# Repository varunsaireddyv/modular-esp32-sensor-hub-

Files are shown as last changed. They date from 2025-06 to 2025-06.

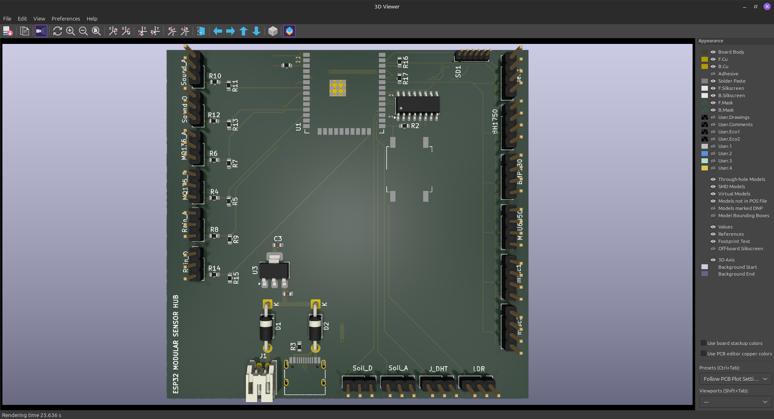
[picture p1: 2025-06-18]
Images/PCB_F.png

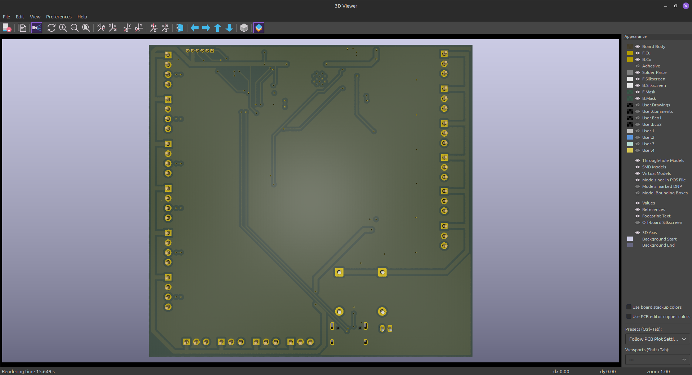
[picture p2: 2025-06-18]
Images/PCB_B.png

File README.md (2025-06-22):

# modular-esp32-sensor-hub-
Introduction:

This project is a modular ESP32-based sensor hub designed for rapid prototyping and monitoring environements. It supports a wide range of sensors through hot-swappable connectors, with onboard SD card logging, and runs off a 5v li-ion battery. The goal is to offer a deployable, plug-and-play embedded system that’s both scalable and user-friendly.

Primary Design Goals:

Modularity:hot-swappable sensor ports for analog, digital, and I2C devices, swapable power source, programable ESP board

Deployability:standalone and swapable power and onboard storage, light weight custom ESP 32 WROOM 32D board

Plug-and-play:Firmware pre installed and no user input required exept for conecting sensors to premaped sensor pins

---

## Features

- ESP32-WROOM-32D core (Wi-Fi + BLE)
- 13 modular sensor ports: digital, analog, and I2C
- MicroSD card support (SPI) for data logging
- 0.96" OLED screen support via I2C
- Shared I2C bus (GPIO21/GPIO22) with pull-up planning
- Dual voltage rails: 5V (VBUS) and 3.3V (via AMS1117 regulator)
- USB or Li-ion battery input with diode-based auto-switching
- Ground stitched bottom layer with dedicated signal routing on top
- Wide traces (1mm) for power, separate analog and digital zones
- Modular firmware (coming soon)

---

## Pin Mapping

| Function | GPIO Pin |
|---|---|
| I2C SDA | GPIO21 |
| I2C SCL | GPIO22 |
| SD Card CS | GPIO5 |
| SD Card CLK | GPIO18 |
| SD Card MOSI | GPIO23 |
| SD Card MISO | GPIO19 |
| Analog Sensor 1 | GPIO32 |
| Analog Sensor 2 | GPIO33 |
| Digital Sensor 1 | GPIO25 |
| Digital Sensor 2 | GPIO26 |
| Digital Sensor 3 | GPIO27 |
| Digital Sensor 4 | GPIO14 |
| Digital Sensor 5 | GPIO12 |
| Digital Sensor 6 | GPIO13 |
| OLED (I2C) | Shared |
| I2C Misc Ports 1-2  | Shared |

> All analog lines use 1k/2k voltage dividers to drop from 5V to 3.3V safe levels for the ESP32. All sensors are routed through XH-3P connectors with GND, VCC, and Signal/I2C.

---

## Supported Sensors(Default in Firmware)

### Analog / Digital Sensors
- MQ135 (Air Quality)
- DHT22 (Temp & Humidity)
- Raindrop Sensor
- Sound Sensor (x2)
- Soil Moisture
- LDR (Light)
- IR Receiver

### I2C Sensors & Modules
- MPU6050 (Accel + Gyro)
- BME280 (Temp + Pressure + Humidity)
- BH1750 (Light)
- OLED Display

---

## Included Files/Folders

- Schematic: `ESP32_WROOM_D.kicad_sch`
- Board Layout: `PCB_main.kicad_pcb`
- Schematic PNG preview: `Schemtaic.png`
- 3D render: `PCB.png`
- 3D render front: `PCB_F.png`
- 3D render back: `PCB_B.png`
- License: MIT
- Firmware: src/, include/,  lib/, "platform.ini"
- Documents: "ERC", "DRC", "Datasheet", "Pin_mapping"

---

## Firmware flow

main.cpp :
-Calls SensorManager.begin() → initializes I2C, sets up pins
-Calls SensorManager.detectConnectedSensors() → auto-detects attached sensors
-Calls SensorManager.readAll() repeatedly inside loop() to read & print sensor data

sensormanger.cpp/.h :
-Defines bool flags for each supported sensor
-Each sensor has its own analogRead() or I2C detection logic
-readAll() only reads sensors that were marked as detected(bool=true)

pins.h :
-Central place to edit pin numbers (for future boards or remapping)
-Also includes notes on analog/digital/I2C mappings

---

## Adding own sensors

You can plug in any new sensor to unused analog/digital/I2C ports. Here’s how to support it in firmware:

Step 1 : Wiring :

-Connect the sensor to a free port (check Pin Mapping table)
-Use correct GND/VCC/SIG (XH-3P)

step 2 : Modify "sensormanger.h" :
   
  -Add a flag for presence detection :
      
    extern bool NEW_SENSOR_present;

step 3 : Modify "pins.h" :
   
  -define your sensor with its GIO pin :
  
    #define NEW_SENSOR_PIN ##   //replace ## with GIO pin(can be found in sensor data sheet)

step 4 : Modify "sensormanger.cpp" :

  -In detectConnectedSensors add :
  
    -if (analogRead(NEW_SENSOR_PIN) > 50) NEW_SENSOR_present = true;   //(for analog sensors)
    -if (analogRead(NEW_SENSOR_PIN) > 50) NEW_SENSOR_present = true;   //(for digital sensors)
    -Check sensor library for I2C (differs from sensor to sensor reffer sesnormanager.cpp for refrence)
   
  -In readAll add :
  
    -if (NEW_SENSOR_present) {
      int val = analogRead(NEW_SENSOR_PIN);   //(for analog)
      }
    -if (NEW_SENSOR_present) {
      int val = digitalRead(NEW_SENSOR_PIN);   //(for analog)
        }
      -Check sensor library for I2C (differs from sensor to sensor reffer sesnormanager.cpp for refrence)

step 5 : SD card logging 

-5.1 : Update sdlogger.h : 

  -In sdlogger.h, go to the writeRow() function declaration. Add your new sensor’s argument at the end:
  
    void writeRow(
        String timestamp,
        ...
        String BH1750,
        String NEW_SENSOR      //<-- Add this
    ) ;

5.2 : Update sdlogger.cpp :

  -Update the writeRow() definition:
  -Add the new parameter to the function like:
  
    void writeRow(
        String timestamp,
        ...
        String BH1750,
        String NEW_SENSOR       //<-- Add here too
    ) {
  -Add it to the file write block:
  -Scroll to where values are written into the file. Append this:

    file.print(NEW_SENSOR); file.println();    //<-- Just before file.close();
  -Update the CSV header:
  -Only needed once, in the same file (inside if (!SD.exists("/logs.csv"))):

    file.println("Time stamp,MQ135-D,MQ135-A,DHT22,RAIN-A,RAIN-D,SOUND-A,SOUND-D,SOIL-A,SOIL-D,MPU6050,BMP180,BH1750,NEW_SENSOR");

5.3 : Modify readAll() in SensorManager :
  -If your sensor is optional/detectable:

    String newSensorValue = "NA";
    if (NEW_SENSOR_present) {
      int val = analogRead(NEW_SENSOR_PIN);  // or digitalRead / I2C
      newSensorValue = String(val);

  -Then pass it to the logger:

    SdLogger::writeRow(
      timestamp,
      mq135_d, mq135_a,
      dht22,
      rain_a, rain_d,
      sound_a, sound_d,
      soil_a, soil_d,
      mpu6050,
      bmp180,
      bh1750,
      newSensorValue       //<-- Final argument
    );
    }

---

## Flashing the Board (PlatformIO)

To upload firmware to the ESP32 board:

1. Install PlatformIO:

   -VSCode + PlatformIO extension
   -Or via CLI: https://platformio.org/install/cli
   
3. Clone this repo:
   
    -git clone https://github.com/varunsaireddyv/modular-esp32-sensor-hub-.git
    -cd modular-esp32-sensor-hub-
   
5. Plug in the board via USB
   
6. Build and upload
    -pio run --target upload

---

## Hardware Design Notes

- 2-layer PCB: Top for signals, Bottom for full GND plane
- GND stitching via multiple vias across zones
- AMS1117 regulator outputs 3.3V rail, with thick trace routing
- Diode-logic used to auto-select between USB or battery power
- All connectors: XH-3P format for modularity
- I2C pull-up resistors placed close to MCU

---

## License

This project is licensed under the MIT License. See `LICENSE` file for full terms.
You may freely modify, distribute, or use this project in your own designs.

## For hire !!
reach out at : varunbillas@gmail.com

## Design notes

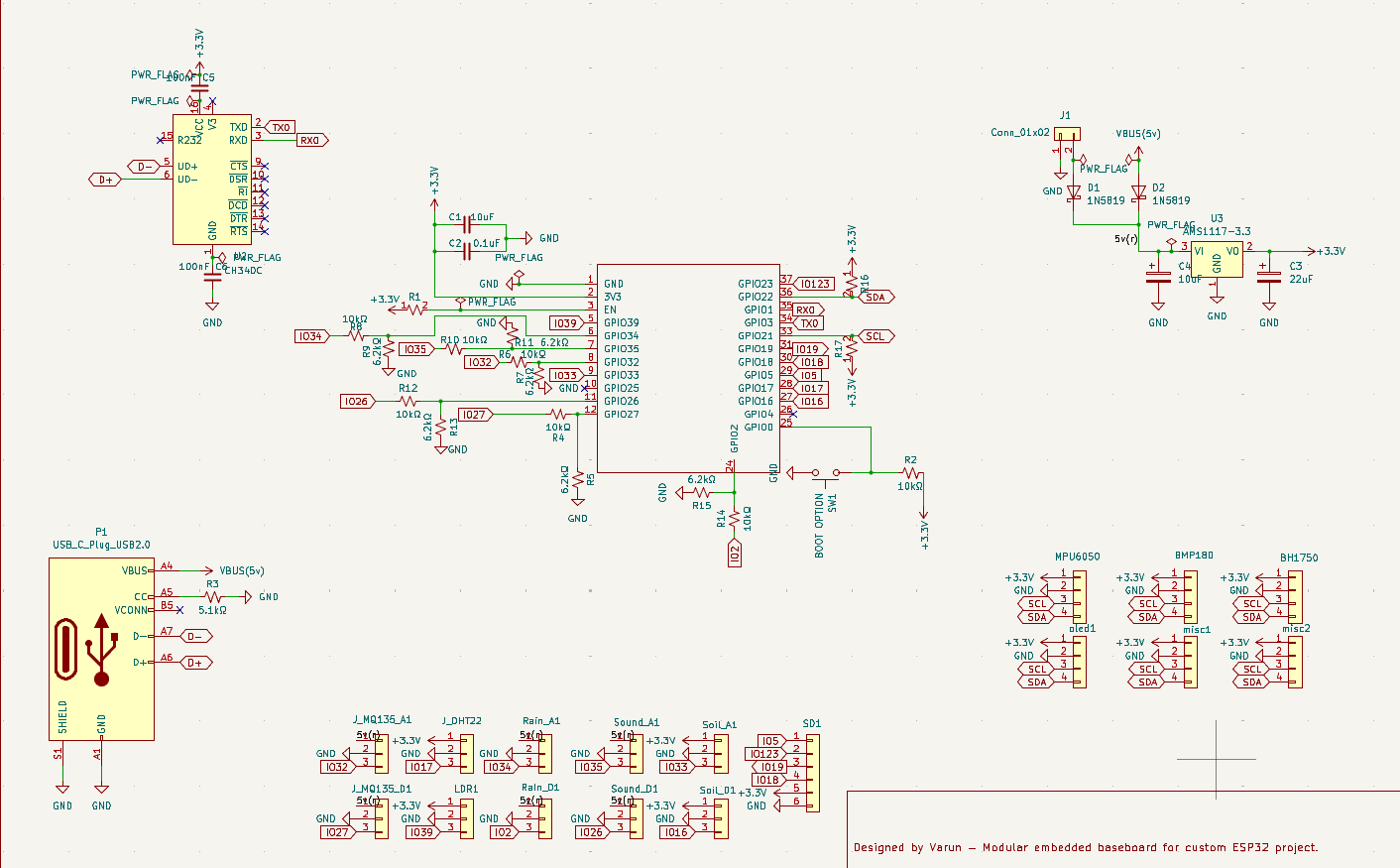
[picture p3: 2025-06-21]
Images/Schematic.png

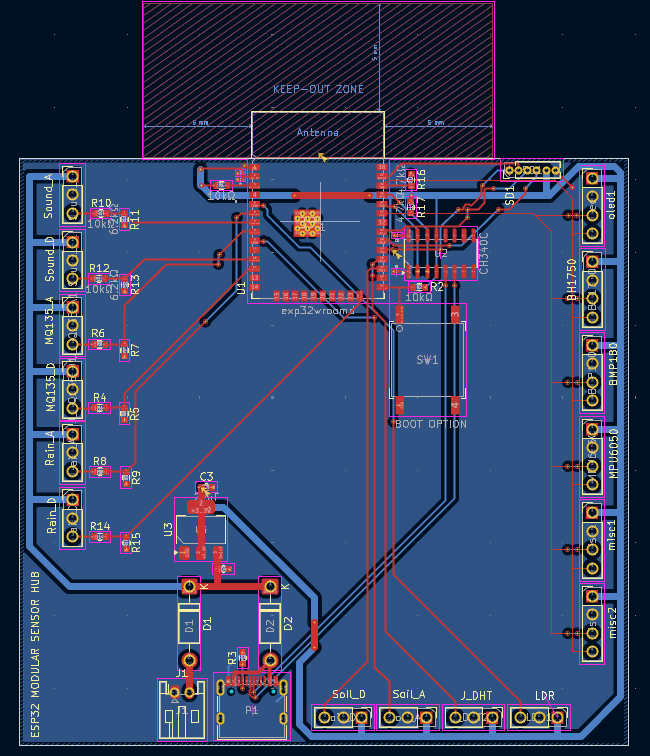
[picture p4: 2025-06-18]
Images/PCB.png

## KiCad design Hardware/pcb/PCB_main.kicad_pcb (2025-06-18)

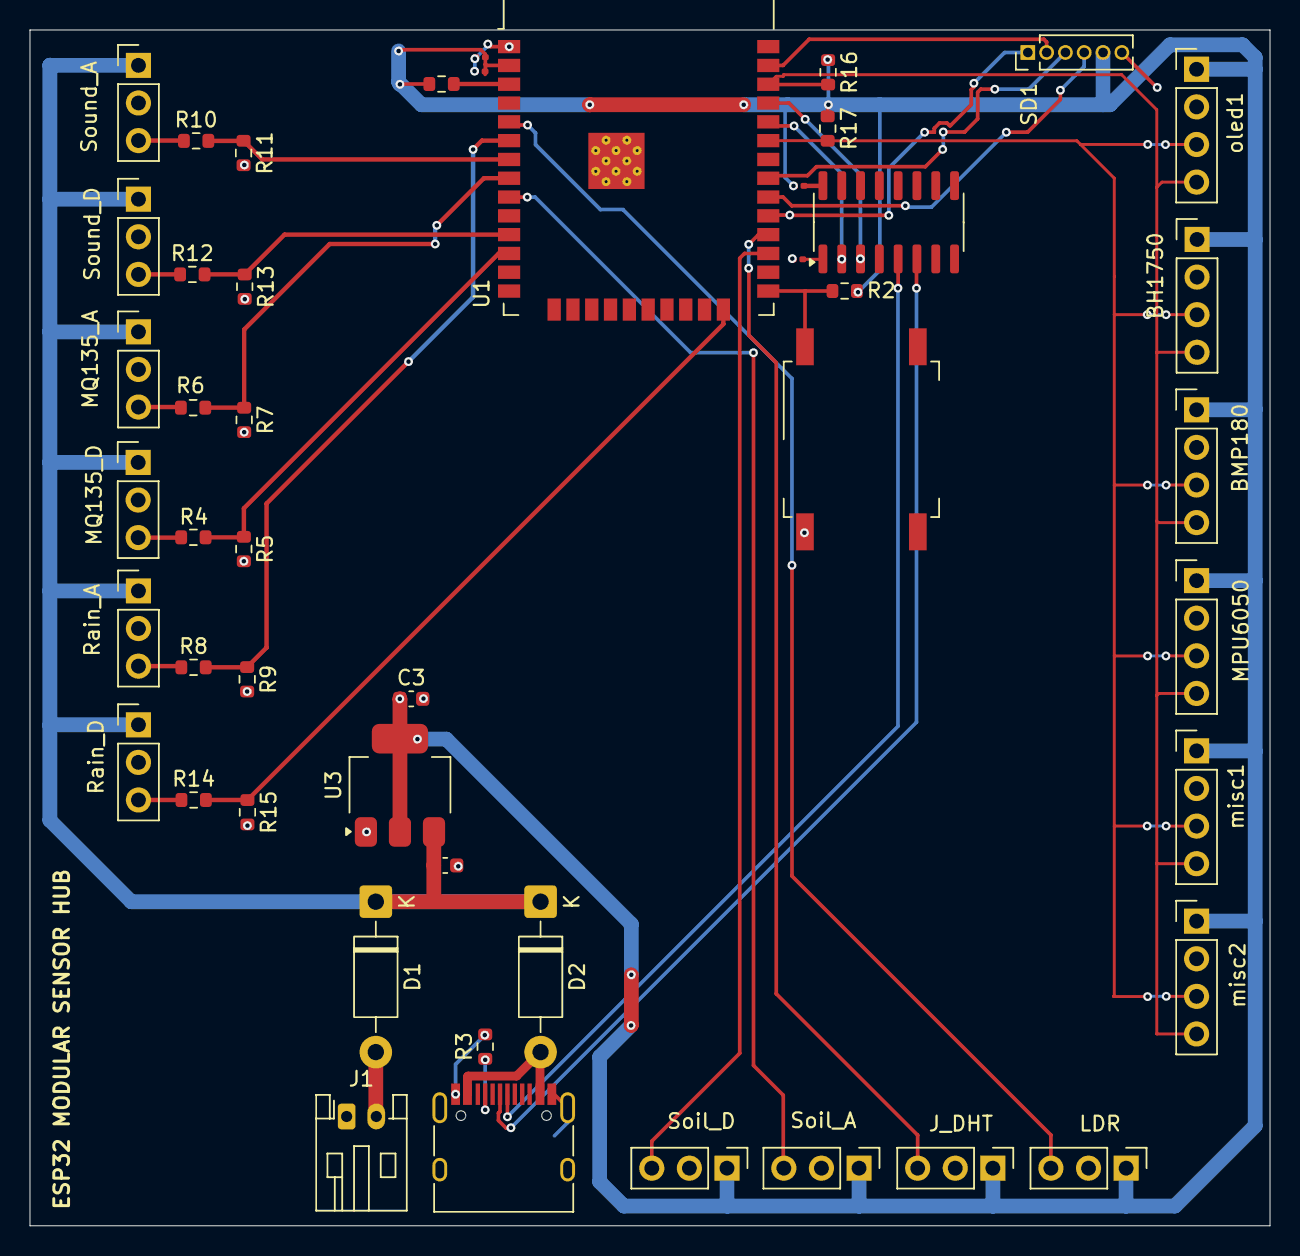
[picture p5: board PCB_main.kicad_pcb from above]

Board: 2 copper layers, 83.8 x 80.8 mm, 48 parts (0 on the bottom side), 36 nets.

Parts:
BH1750: Conn_01x04; PinHeader_1x04_P2.54mm_Vertical
BMP180: Conn_01x04; PinHeader_1x04_P2.54mm_Vertical
C1: 10uF; C_0201_0603Metric
C2: 0.1uF; C_0201_0603Metric
C3: 22uF; C_0603_1608Metric
C4: 10uF; C_0603_1608Metric
C5, C6: 100nF; C_0201_0603Metric
D1, D2: 1N5819; D_DO-41_SOD81_P10.16mm_Horizontal
J1: Conn_01x02; JST_PH_S2B-PH-K_1x02_P2.00mm_Horizontal
J_DHT: Conn_01x03; PinHeader_1x03_P2.54mm_Vertical
LDR: Conn_01x03; PinHeader_1x03_P2.54mm_Vertical
MPU6050: Conn_01x04; PinHeader_1x04_P2.54mm_Vertical
MQ135_A, MQ135_D: Conn_01x03; PinHeader_1x03_P2.54mm_Vertical
P1: USB_C_Plug_USB2.0; USB_C_Receptacle_HRO_TYPE-C-31-M-12
R1, R2, R4, R6, R8, R10, R12, R14: 10kΩ; R_0603_1608Metric
R3: 5.1kΩ; R_0603_1608Metric
R5, R7, R9, R11, R13, R15: 6.2kΩ; R_0603_1608Metric
R16, R17: 4.7kΩ; R_0603_1608Metric
Rain_A: Conn_01x03; PinHeader_1x03_P2.54mm_Vertical
Rain_D: Conn_01x03; PinHeader_1x03_P2.54mm_Vertical
SD1: Conn_01x06; PinHeader_1x06_P1.27mm_Vertical
SW1: BOOT OPTION; SW_MEC_5GSH9
Soil_A: Conn_01x03; PinHeader_1x03_P2.54mm_Vertical
Soil_D: Conn_01x03; PinHeader_1x03_P2.54mm_Vertical
Sound_A: Conn_01x03; PinHeader_1x03_P2.54mm_Vertical
Sound_D: Conn_01x03; PinHeader_1x03_P2.54mm_Vertical
U1: exp32wroomd; ESP32-WROOM-32D
U2: CH340C; SOIC-16_3.9x9.9mm_P1.27mm
U3: AMS1117-3.3; SOT-223-3_TabPin2
misc1, misc2: Conn_01x04; PinHeader_1x04_P2.54mm_Vertical
oled1: Conn_01x04; PinHeader_1x04_P2.54mm_Vertical

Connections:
+3.3V: BH1750.1, BMP180.1, C1.1, C2.1, C3.1, C5.2, J_DHT.1, LDR.1, MPU6050.1, R1.1, R2.2, R16.1, R17.1, SD1.5, Soil_A.1, Soil_D.1, U1.2 (3V3), U3.2 (VO), misc1.1, misc2.1, oled1.1
/5v(r): C4.1, D1.1 (K), D2.1 (K), MQ135_A.1, MQ135_D.1, Rain_A.1, Rain_D.1, Sound_A.1, Sound_D.1, U3.3 (VI)
D+: P1.A6 (D+), U2.6 (UD-)
D-: P1.A7 (D-), U2.5 (UD+)
GND: BH1750.2, BMP180.2, C1.2, C2.2, C3.2, C4.2, C6.1, J1.1, J_DHT.2, LDR.2, MPU6050.2, MQ135_A.2, MQ135_D.2, P1.A1 (GND), P1.A12 (GND), P1.B1 (GND), P1.B12 (GND), P1.S1 (SHIELD), R3.2, R5.2, R7.2, R9.2, R11.2, R13.2, R15.2, Rain_A.2, Rain_D.2, SD1.6, SW1.2, Soil_A.2, Soil_D.2, Sound_A.2, Sound_D.2, U1.1 (GND), U3.1 (GND), misc1.2, misc2.2, oled1.2
IO2: R14.1, Rain_D.3
IO5: SD1.1, U1.29 (GPIO5)
IO16: Soil_D.3, U1.27 (GPIO16)
IO17: J_DHT.3, U1.28 (GPIO17)
IO18: SD1.4, U1.30 (GPIO18)
IO19: SD1.3, U1.31 (GPIO19)
IO26: R12.1, Sound_D.3
IO27: MQ135_D.3, R4.1
IO32: MQ135_A.3, R6.1
IO33: Soil_A.3, U1.9 (GPIO33)
IO34: R8.1, Rain_A.3
IO35: R10.1, Sound_A.3
IO39: LDR.3, U1.5 (GPIO39)
IO123: SD1.2, U1.37 (GPIO23)
unnamed: D1.2 (A), J1.2
unnamed: P1.A5 (CC), R3.1
unnamed: R1.2, U1.3 (EN)
unnamed: R2.1, SW1.1, U1.25 (GPIO0)
unnamed: R14.2, R15.1, U1.24 (GPIO2)
unnamed: R12.2, R13.1, U1.11 (GPIO26)
unnamed: R4.2, R5.1, U1.12 (GPIO27)
unnamed: R6.2, R7.1, U1.8 (GPIO32)
unnamed: R8.2, R9.1, U1.6 (GPIO34)
unnamed: R10.2, R11.1, U1.7 (GPIO35)
unnamed: C6.2, U2.1 (GND)
unnamed: C5.1, U2.16 (VCC)
RX0: U1.35 (GPIO1), U2.3 (RXD)
SCL: BH1750.3, BMP180.3, MPU6050.3, R17.2, U1.33 (GPIO21), misc1.3, misc2.3, oled1.3
SDA: BH1750.4, BMP180.4, MPU6050.4, R16.2, U1.36 (GPIO22), misc1.4, misc2.4, oled1.4
TX0: U1.34 (GPIO3), U2.2 (TXD)
VBUS(5v): D2.2 (A), P1.A4 (VBUS), P1.A9 (VBUS), P1.B4 (VBUS), P1.B9 (VBUS)

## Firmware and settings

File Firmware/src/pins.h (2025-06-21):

#ifndef PINS_H
#define PINS_H

// I2C Shared Bus
#define I2C_SDA 21
#define I2C_SCL 22

// Analog Sensors (ADC)
#define MQ135_A1_PIN 32
#define DHT22_PIN    27
#define RAIN_A1_PIN  35
#define SOUND_A1_PIN 34
#define SOIL_A1_PIN  36

// Digital Sensors
#define MQ135_D1_PIN 39
#define RAIN_D1_PIN  26
#define SOUND_D1_PIN 25
#define SOIL_D1_PIN  16

// Optional: Status LED or future use
#define STATUS_LED   2

#endif

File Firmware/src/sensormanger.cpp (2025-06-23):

#include "sensormanger.h"
#include <Wire.h>
#include "pins.h"
#include "sdlogger.h" // make sure this is included at the top


MPU6050 mpu;
Adafruit_BMP085 bmp;
BH1750 lightMeter;

bool MQ135a_present = false;
bool MQ135d_present = false;
bool DHT22_present = false;
bool RAINa_present = false;
bool RAINd_present = false;
bool SOUNDa_present = false;
bool SOUNDd_present = false;
bool SOILa_present = false;
bool SOILd_present = false;

bool MPU6050_present = false;
bool BMP180_present = false;
bool BH1750_present = false;
bool OLED_present = false;




void SensorManager::begin() {

    // Setup pins
    pinMode(MQ135_D1_PIN, INPUT);
    pinMode(RAIN_D1_PIN, INPUT);
    pinMode(SOUND_D1_PIN, INPUT);
    pinMode(SOIL_D1_PIN, INPUT);


}


void SensorManager::detectConnectedSensors() {

    // Format sensor readings
    String mq135_d = MQ135d_present ? String(digitalRead(MQ135_D1_PIN)) : "NA";
    String mq135_a = MQ135a_present ? String(analogRead(MQ135_A1_PIN)) : "NA";
    String dht22    = DHT22_present  ? String(analogRead(DHT22_PIN)) : "NA";
    String rain_a   = RAINa_present  ? String(analogRead(RAIN_A1_PIN)) : "NA";
    String rain_d   = RAINd_present  ? String(digitalRead(RAIN_D1_PIN)) : "NA";
    String sound_a  = SOUNDa_present ? String(analogRead(SOUND_A1_PIN)) : "NA";
    String sound_d  = SOUNDd_present ? String(digitalRead(SOUND_D1_PIN)) : "NA";
    String soil_a   = SOILa_present  ? String(analogRead(SOIL_A1_PIN)) : "NA";
    String soil_d   = SOILd_present  ? String(digitalRead(SOIL_D1_PIN)) : "NA";

    // MPU6050 (show only Accel X )
    String mpu6050 = "NA";
    if (MPU6050_present) {
        int16_t ax, ay, az;
        mpu.getAcceleration(&ax, &ay, &az);
        mpu6050 = "AX:" + String(ax) + ",AY:" + String(ay) + ",AZ:" + String(az);
    }

    // BMP180
    String bmp180 = "NA";
    if (BMP180_present) {
        float temp = bmp.readTemperature();
        int pressure = bmp.readPressure();
        bmp180 = String(temp, 1) + "C " + String(pressure) + "Pa";
    }

    // BH1750
    String bh1750 = BH1750_present ? String(lightMeter.readLightLevel(), 1) + "lx" : "NA";

    // FINAL WRITE
    SdLogger::writeRow(
        timestamp,
        mq135_d, mq135_a,
        dht22,
        rain_a, rain_d,
        sound_a, sound_d,
        soil_a, soil_d,
        mpu6050,
        bmp180,
        bh1750
    );


}

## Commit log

2025-06-15 Add placeholder files to track empty directories
2025-06-16 Updated schematic
    [ESP32_WROOM_D.kicad_sch]
2025-06-17 PCB base
    [Pcb_main.kicad_pcb]
2025-06-18 PCB Final
    [ESP32_WROOM_D.kicad_sch, PCB_main.kicad_pcb]
2025-06-22 src completed
    [logs.csv]
